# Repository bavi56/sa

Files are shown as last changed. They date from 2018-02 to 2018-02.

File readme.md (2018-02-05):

# Servisní analyzátor s arduino Nano

* 8x 24V digitalni vstup
* 3x analogový vstup pro SCT013

## Firmware

[arduino Nano](./sa.ino)

Odkomentovat pro čitelný výpis do serial monitoru:
```c++
#define DEBUG
```

Seznam součástek [zde](./eagle/partlist.txt).

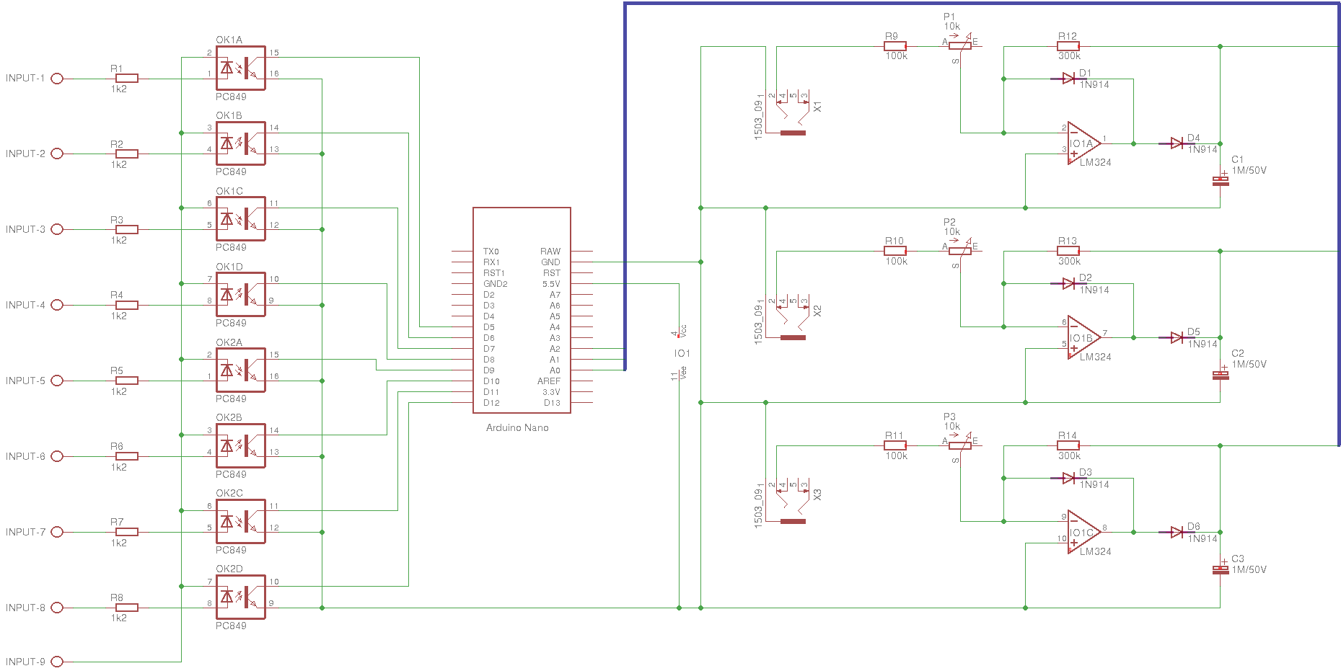
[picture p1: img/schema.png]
Schéma


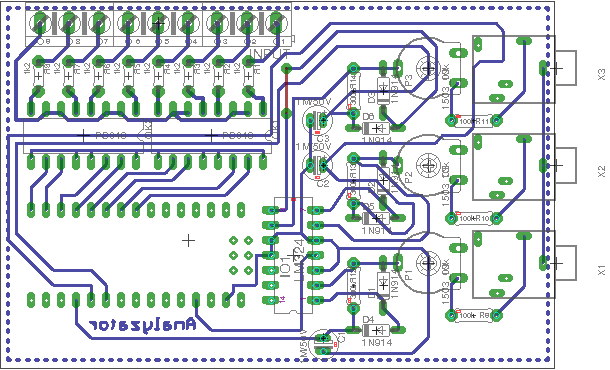
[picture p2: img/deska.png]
Deska


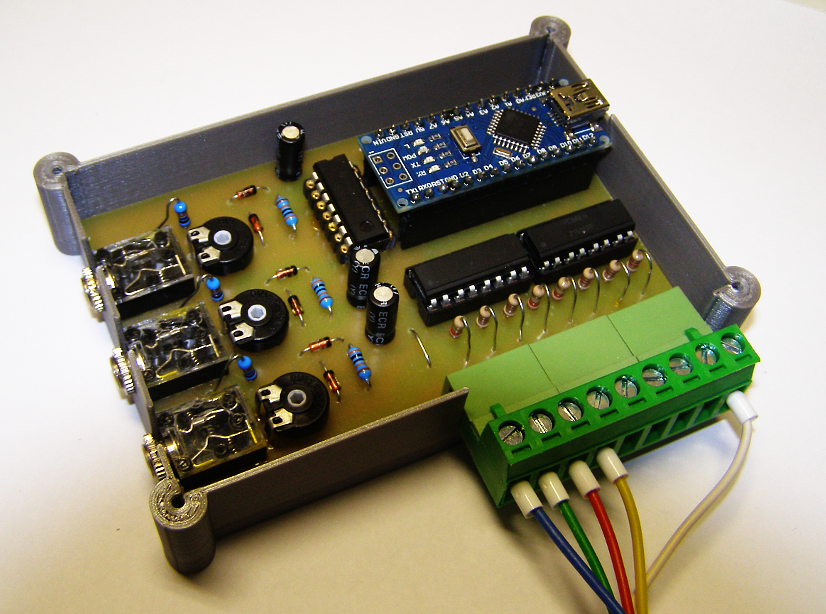
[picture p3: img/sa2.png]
Strana soucastek


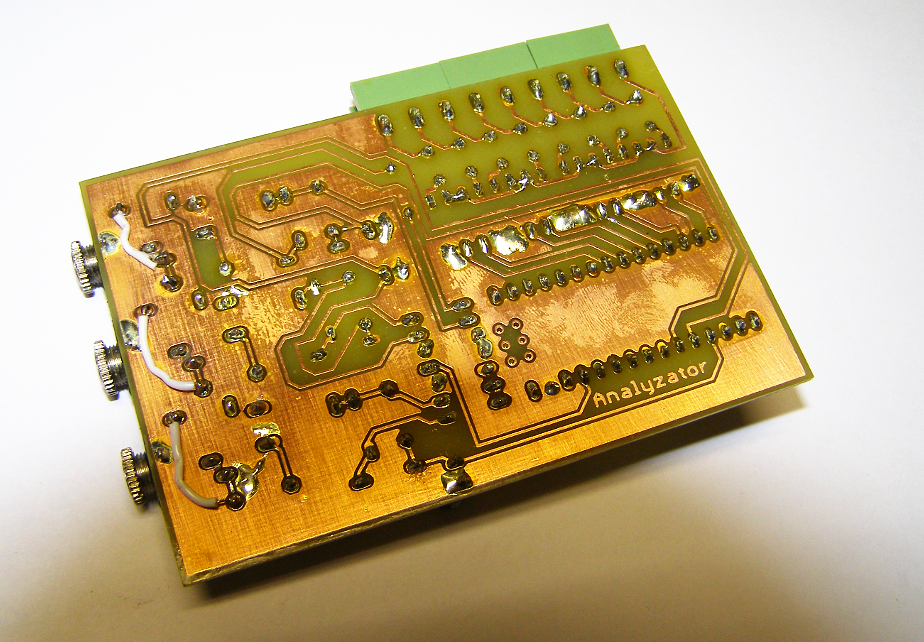
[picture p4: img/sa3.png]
Strana spoju


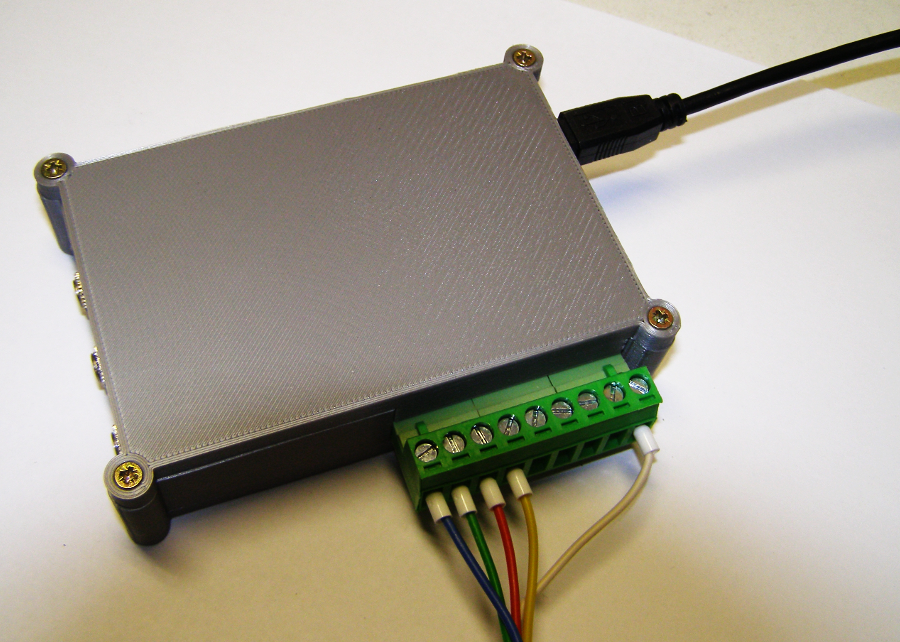
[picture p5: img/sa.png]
Sestaveno


## Zobrazení

* ### processing [zde](./processing/sa_java.pde)

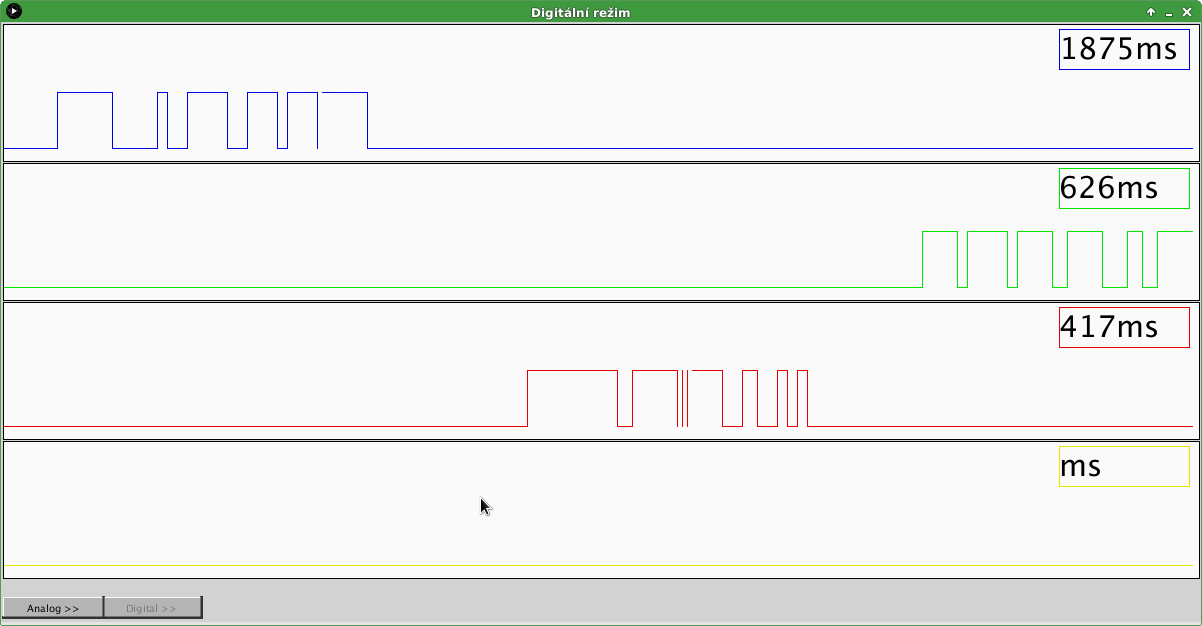
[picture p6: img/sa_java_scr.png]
Processing


* ### python [zde](./sa.pyw) (potřeba stáhnout modul [pygraf](https://github.com/blindp/pygraf) a mít nainstalovaný tkinter)

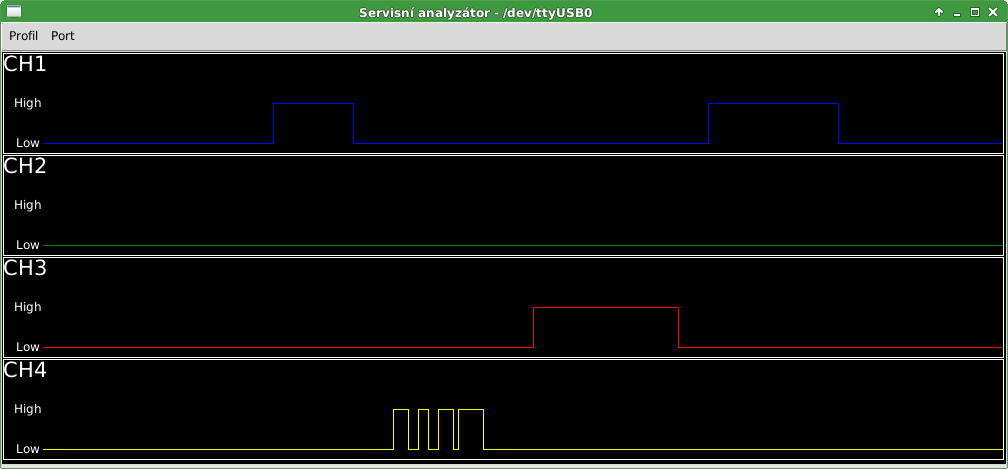
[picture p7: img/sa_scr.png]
SaPy


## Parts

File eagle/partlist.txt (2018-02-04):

Partlist

Exported from s_analyzer.sch at 04.02.18 13:12

EAGLE Version 7.6.0 Copyright (c) 1988-2016 CadSoft

Assembly variant: 

Part     Value          Device       Package  Library       Sheet

C1       1M/50V         1M/50V       C_EL_2   #PaJa_C-el_2  1
C2       1M/50V         1M/50V       C_EL_2   #PaJa_C-el_2  1
C3       1M/50V         1M/50V       C_EL_2   #PaJa_C-el_2  1
D1       1N914          1N4148DO35-7 DO35-7   diode         1
D2       1N914          1N4148DO35-7 DO35-7   diode         1
D3       1N914          1N4148DO35-7 DO35-7   diode         1
D4       1N914          1N4148DO35-7 DO35-7   diode         1
D5       1N914          1N4148DO35-7 DO35-7   diode         1
D6       1N914          1N4148DO35-7 DO35-7   diode         1
INPUT                   AK500/9      AK500/9  #Svorkovnice  1
IO1      LM324          LM324        DIL14    #PaJa_31      1
OK1      PC849          PC849        DIL16    optocoupler   1
OK2      PC849          PC849        DIL16    optocoupler   1
P1       10k            TRIMRPT10V   PT10V    #Trimry       1
P2       10k            TRIMRPT10V   PT10V    #Trimry       1
P3       10k            TRIMRPT10V   PT10V    #Trimry       1
R1       1k2            R-EU_0204/5  0204/5   #Odpory       1
R2       1k2            R-EU_0204/5  0204/5   #Odpory       1
R3       1k2            R-EU_0204/5  0204/5   #Odpory       1
R4       1k2            R-EU_0204/5  0204/5   #Odpory       1
R5       1k2            R-EU_0204/5  0204/5   #Odpory       1
R6       1k2            R-EU_0204/5  0204/5   #Odpory       1
R7       1k2            R-EU_0204/5  0204/5   #Odpory       1
R8       1k2            R-EU_0204/5  0204/5   #Odpory       1
R9       100k           330K         R_7,5    #PaJa_R       1
R10      100k           330K         R_7,5    #PaJa_R       1
R11      100k           330K         R_7,5    #PaJa_R       1
R12      300k           100K         R_7,5    #PaJa_R       1
R13      300k           100K         R_7,5    #PaJa_R       1
R14      300k           100K         R_7,5    #PaJa_R       1
U$1      NANO           NANO         NANO     Arduino-clone 1
X1       1503_09        1503_09      1503_09  con-lumberg   1
X2       1503_09        1503_09      1503_09  con-lumberg   1
X3       1503_09        1503_09      1503_09  con-lumberg   1

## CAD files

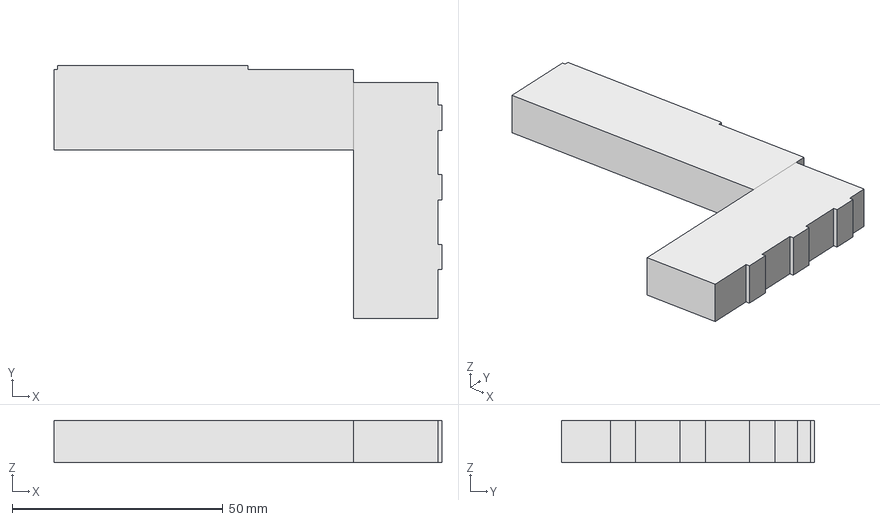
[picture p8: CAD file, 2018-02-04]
freeCAD/krabicka_sa.fcstd
92.0 x 60.0 x 10.0 mm

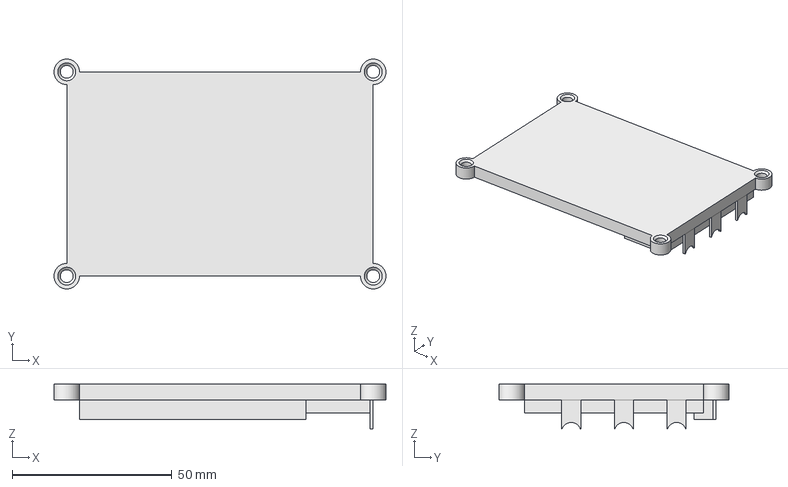
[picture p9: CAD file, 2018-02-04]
freeCAD/vicko_sa.fcstd
104.0 x 72.0 x 14.0 mm

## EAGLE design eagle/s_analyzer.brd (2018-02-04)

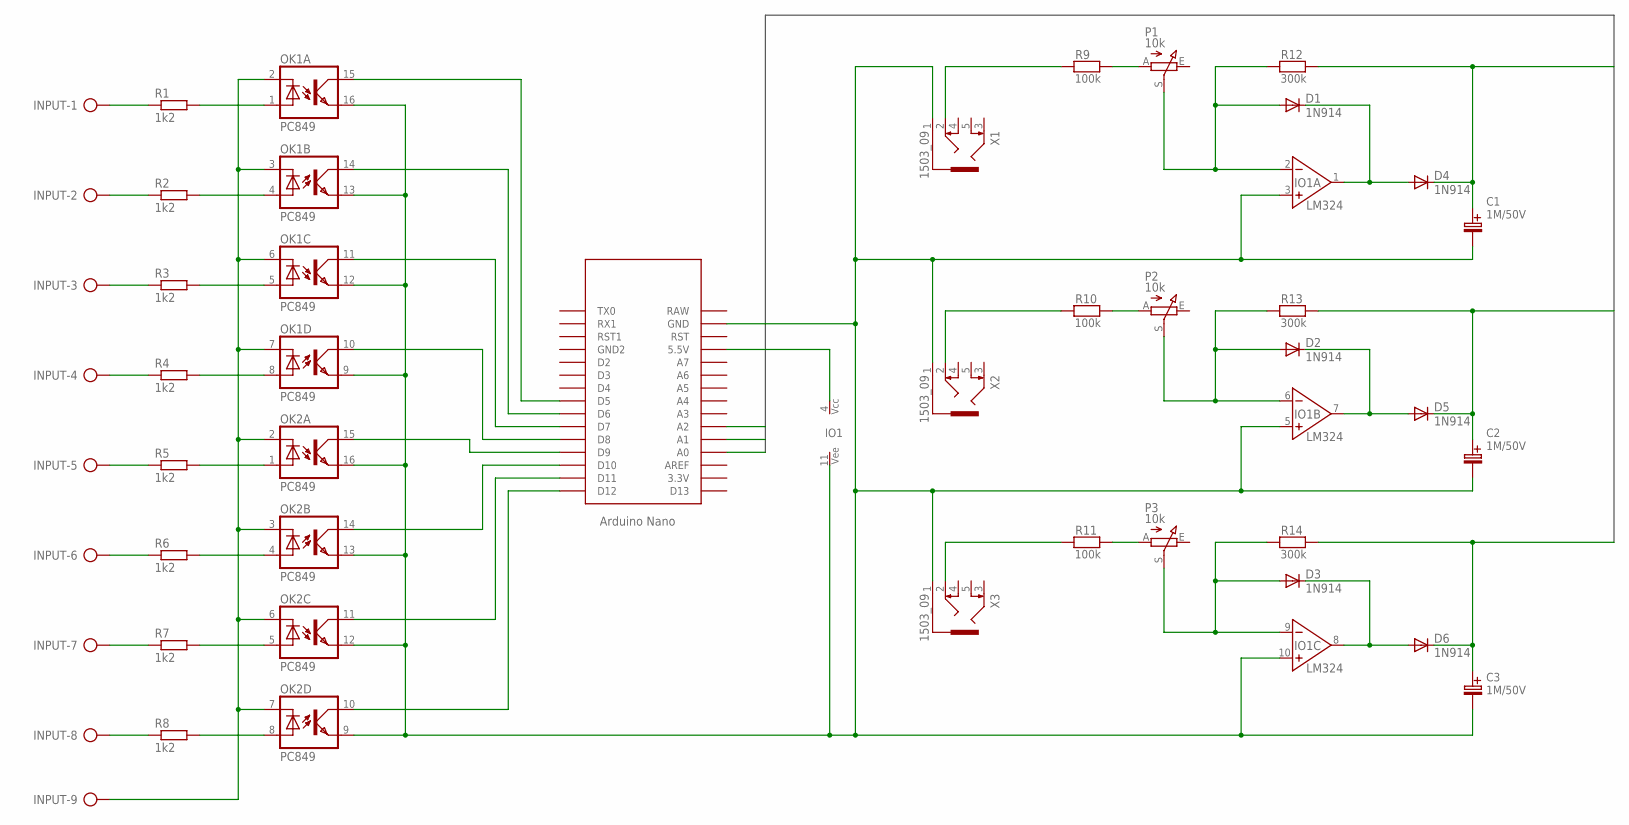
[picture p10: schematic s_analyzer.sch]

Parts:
C1, C2, C3: 1M/50V; C_EL_2
D1, D2, D3, D4, D5, D6: 1N914; DO35-7
INPUT: AK500/9
IO1: LM324; DIL14
OK1, OK2: PC849; DIL16
P1, P2, P3: 10k; PT10V
R1, R2, R3, R4, R5, R6, R7, R8: 1k2; 0204/5
R9, R10, R11: 100k; R_7,5
R12, R13, R14: 300k; R_7,5
U$1: NANO
X1, X2, X3: 1503_09

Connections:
A0: C1.C+ (C_EL+), D4.C, R12.2, U$1.A0
A1: C2.C+ (C_EL+), D5.C, R13.2, U$1.A1
A2: C3.C+ (C_EL+), D6.C, R14.2, U$1.A2
unnamed: INPUT.1, R1.1
unnamed: OK1.1 (A), R1.2
unnamed: INPUT.2, R2.1
unnamed: OK1.4 (A), R2.2
unnamed: INPUT.3, R3.1
unnamed: OK1.5 (A), R3.2
unnamed: INPUT.4, R4.1
unnamed: OK1.8 (A), R4.2
unnamed: INPUT.5, R5.1
unnamed: OK2.1 (A), R5.2
unnamed: INPUT.6, R6.1
unnamed: OK2.4 (A), R6.2
unnamed: INPUT.7, R7.1
unnamed: OK2.5 (A), R7.2
unnamed: INPUT.8, R8.1
unnamed: OK2.8 (A), R8.2
unnamed: INPUT.9, OK1.2 (C), OK1.3 (C), OK1.6 (C), OK1.7 (C), OK2.2 (C), OK2.3 (C), OK2.6 (C), OK2.7 (C)
unnamed: IO1.4 (VCC), U$1.5V (5.5V)
unnamed: OK2.10 (COL), U$1.D12
unnamed: OK2.11 (COL), U$1.D11
unnamed: OK2.14 (COL), U$1.D10
unnamed: OK2.15 (COL), U$1.D9
unnamed: OK1.10 (COL), U$1.D8
unnamed: OK1.11 (COL), U$1.D7
unnamed: OK1.14 (COL), U$1.D6
unnamed: OK1.15 (COL), U$1.D5
unnamed: D1.A, IO1.2 (IN-), P1.S, R12.1
unnamed: P1.A, R9.2
unnamed: D1.C, D4.A, IO1.1 (VYSTUP)
unnamed: R11.1, X3.2
unnamed: P2.A, R10.2
unnamed: D2.A, IO1.6 (IN-), P2.S, R13.1
unnamed: D2.C, D5.A, IO1.7 (VYSTUP)
unnamed: R10.1, X2.2
unnamed: P3.A, R11.2
unnamed: D3.A, IO1.9 (IN-), P3.S, R14.1
unnamed: D3.C, D6.A, IO1.8 (VYSTUP)
unnamed: R9.1, X1.2
unnamed: C1.C- (C_EL-), C2.C- (C_EL-), C3.C- (C_EL-), IO1.3 (NEIN+), IO1.5 (NEIN+), IO1.10 (NEIN+), IO1.11 (VEE), OK1.9 (EMI), OK1.12 (EMI), OK1.13 (EMI), OK1.16 (EMI), OK2.9 (EMI), OK2.12 (EMI), OK2.13 (EMI), OK2.16 (EMI), U$1.GND, X1.1, X2.1, X3.1

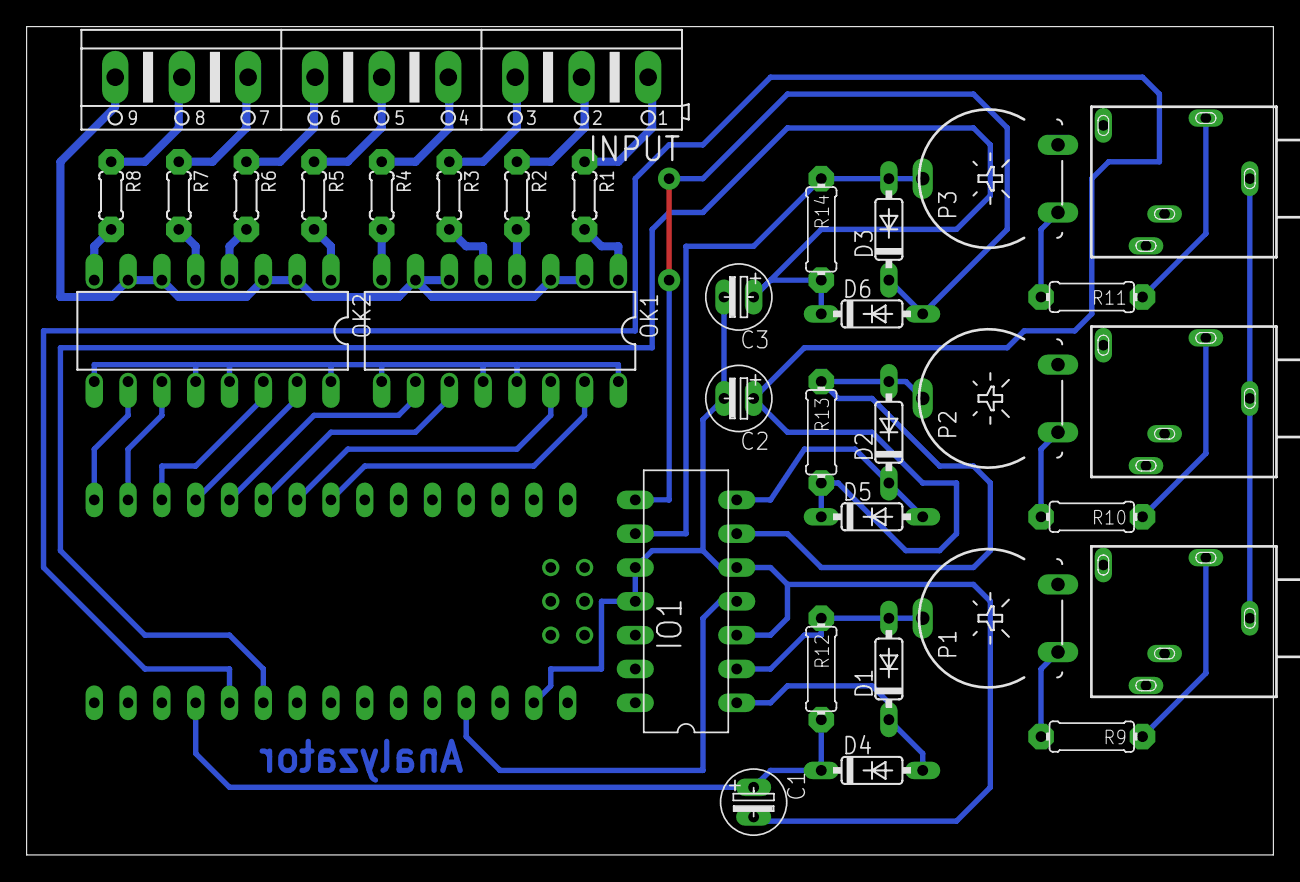
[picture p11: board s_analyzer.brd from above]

Board: 2 copper layers, 93.6 x 62.2 mm, 34 parts (0 on the bottom side), 42 nets.

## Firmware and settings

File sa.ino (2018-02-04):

/*Firmware pro servisni analyzator verze 1
 * 8x 24V digitalni vstup
 * 3 analogove (prevodnik proudovy transformator SCT013 www.yhdc.com (0-5A -> 0-1V))
 * Blind Pew <blind.pew96@gmail.com> 2016 GNU GPL v3
 */

//#define DEBUG
#define BRATE 115200
#define MIN_ADC 0
#define MAX_ADC 1023
#define MIN_ANALOG  0
#define MAX_ANALOG  5000
#ifdef DEBUG
  #define DELAY_DIGITAL 1000
  #define DELAY_ANALOG 1000
#else
  #define DELAY_DIGITAL 5
  #define DELAY_ANALOG  50
#endif
 
byte ovlByte = 0;
bool digital = true;  //rezim true - digitalni | false - analogovy
byte digPins[] = {5,6,7,8,9,10,11,12}; //24V vstupy 
byte anaPins[] = {A0,A1,A2};  //proudove vstupy
byte stav;  //byte 24V vstupu

void setup() {
  Serial.begin(BRATE);
  for(int i=0;i<sizeof(digPins);i++) {
    pinMode(digPins[i],INPUT_PULLUP);
  }
}

void loop() {
  if(Serial.available() > 0) {
    ovlByte = Serial.read();
    if(ovlByte == 'D') digital = true;
    if(ovlByte == 'A') digital = false;
  }
  
  if(digital) {
    for(int i=0;i<8;i++) {
      bitWrite(stav,i,!digitalRead(digPins[i]));
      #ifdef DEBUG
        Serial.print(!digitalRead(digPins[i]));
      #endif
    }
    #ifdef DEBUG    
      Serial.print("-->>");
      Serial.println(stav);
    #else
      Serial.write(stav);
    #endif
    delay(DELAY_DIGITAL);
  }
  else {
    for(int i=0;i<3;i++) {
      Serial.print(map(analogRead(i),MIN_ADC,MAX_ADC,MIN_ANALOG,MAX_ANALOG));
      Serial.print(";");
    }
    Serial.println("");
    delay(DELAY_ANALOG);
  }
}

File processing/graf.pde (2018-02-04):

//Plny graf
class GrafPlny {
  int lmin,lmax,dilku,inc_d,t_size;
  float xpos,ypos,xsize,ysize;
  float[] level;
  color bck,frg,ink;
  boolean auto;
  
  //konstruktor
  GrafPlny(float x_p, float y_p, float x_s,float y_s, color barva,int nula, int maximum) { //vytvori novy graf
    xpos = x_p;  //souradnice noveho grafu
    ypos = y_p;
    xsize = x_s;  //velikost noveho grafu
    ysize = y_s;
    level = new float[int(xsize)]; //vytvori pole o delce sire grafu
    dilku = 15;  //kolik dilku chci mit na stupnici
    inc_d = 1;
    bck = 250;  //barva pozadi
    frg = 0;    //barva popredi
    ink = barva;  //barva grafu
    t_size = 10;  //velikost pisma
    auto = false;
    if(maximum > 0) {
      lmin = nula;
      lmax = maximum;
    }
    else {
      auto = true;
    }
    
  }
  
  void kresli(float l) {
    textAlign(LEFT, BASELINE);
    strokeWeight(1);
    noStroke();
    fill(bck);
    rect(xpos,ypos,xsize,ysize);
    
    if(auto) {
      //urceni min-max hodnoty pro graf
      if(l < lmin) lmin = round(l);
      if(l > lmax) lmax = round(l);
    }
    //posunuti pole o jednu hodnotu zpet (vytvori misto pro novou hodnotu)
    for (int i = 1; i < level.length; i++) {
      level[i-1] = level[i];
    }
    level[level.length-1] = l; //na posledni mmisto prida novou hodnotu
    
    //vykresli cely graf
    for (int i = 0; i < level.length; i++) {
      float yg = map(level[i],lmin,lmax,ypos+ysize,ypos);
      stroke(ink);
      line(i+xpos,ypos+ysize,i+xpos,yg);
    }
    //vykresli stupnici
    fill(bck);
    stroke(frg);
    rect(xpos,ypos,50,ysize);
    stroke(frg);
    if(lmax > dilku) {
      inc_d = lmax/dilku;
    }
    else {
      inc_d = 1;
    }
    for (int i = lmin; i < lmax; i +=inc_d) {
      float ydilek = map(i,lmin,lmax,ypos+ysize,ypos);
      line(xpos+30,ydilek,xpos+50,ydilek);
      for (float x = xpos+50; x < xpos+xsize; x +=5) {
        point(x,ydilek);
      }
      fill(frg);
      textSize(t_size);
      text(floor(i),xpos+5,ydilek-1);
      
    }
    
    //zobrazeni aktualni hodnoty
    fill(bck);
    stroke(ink);
    rect(xpos+xsize-130,ypos+5,120,40);
    fill(frg);
    textSize(30);
    text(l,xpos+xsize-130,ypos+35);
    
    noFill();
    stroke(frg);
    //ram
    rect(xpos,ypos,xsize,ysize);
    
  }
}




//cara
class Graf {
  int lmin,lmax,dilku,inc_d,t_size;
  float xpos,ypos,xsize,ysize;
  float[] level;
  color bck,frg,ink;
  boolean auto;
  
  //konstruktor
  Graf(float x_p, float y_p, float x_s,float y_s, color barva,int nula, int maximum) { //vytvori novy graf
    xpos = x_p;  //souradnice noveho grafu
    ypos = y_p;
    xsize = x_s;  //velikost noveho grafu
    ysize = y_s;
    level = new float[int(xsize)]; //vytvori pole o delce sire grafu
    dilku = 15;  //kolik dilku chci mit na stupnici
    inc_d = 1;
    bck = 250;  //barva pozadi
    frg = 0;    //barva popredi
    ink = barva;  //barva grafu
    t_size = 10;  //velikost pisma
    auto = false;
    if(maximum > 0) {
      lmin = nula;
      lmax = maximum;
    }
    else {
      auto = true;
    }
    
  }
  
  void kresli(float l) {
    textAlign(LEFT, BASELINE);
    strokeWeight(1);
    noStroke();
    fill(bck);
    rect(xpos,ypos,xsize,ysize);
    
    if(auto) {
      //urceni min-max hodnoty pro graf
      if(l < lmin) lmin = round(l);
      if(l > lmax) lmax = round(l);
    }
    //posunuti pole o jednu hodnotu zpet (vytvori misto pro novou hodnotu)
    for (int i = 1; i < level.length; i++) {
      level[i-1] = level[i];
    }
    level[level.length-1] = l; //na posledni mmisto prida novou hodnotu
    float xg_p = 0;
    float yg_p = 0;
    //vykresli cely graf
    for (int i = 0; i < level.length; i++) {
      float xg = map(i, 0, level.length,xpos,xsize);
      float yg = map(level[i],lmin,lmax,ypos+ysize,ypos);
      if((xg_p == 0) && (yg_p == 0)) {
        xg_p = xg;
        yg_p = yg;
      }
      stroke(ink);
      line(xg_p,yg_p,xg,yg);
      xg_p = xg;
      yg_p = yg;
    }
    //vykresli stupnici
    fill(bck);
    stroke(frg);
    rect(xpos,ypos,50,ysize);
    stroke(frg);
    if(lmax > dilku) {
      inc_d = lmax/dilku;
    }
    else {
      inc_d = 1;
    }
    for (int i = lmin; i < lmax; i +=inc_d) {
      float ydilek = map(i,lmin,lmax,ypos+ysize,ypos);
      line(xpos+30,ydilek,xpos+50,ydilek);
      for (float x = xpos+50; x < xpos+xsize; x +=5) {
        point(x,ydilek);
      }
      fill(frg);
      textSize(t_size);
      text(floor(i),xpos+5,ydilek-1);
    }
    
    //zobrazeni aktualni hodnoty
    fill(bck);
    stroke(ink);
    rect(xpos+xsize-130,ypos+5,120,40);
    fill(frg);
    textSize(30);
    text(l,xpos+xsize-130,ypos+35);
    
    
    noFill();
    stroke(frg);
    rect(xpos,ypos,xsize,ysize);
    
  }
}





//vrati vysku grafu
float vyska_y(boolean stav, float sirka, float offset) {
  
  if(stav) {
    return (sirka/2)+offset;
  }
  else {
    return (sirka/1.1)+offset;
  }
}

class Digital {
  long ts_up, ts_dw;
  float xpos,ypos,xsize,ysize;
  boolean[] level;
  color bck,frg,ink;
  String msg;
  
  //kostruktor
  Digital(float x_p, float y_p, float x_s,float y_s, color barva) { //vytvori novy graf
    xpos = x_p;  //souradnice noveho grafu
    ypos = y_p;
    xsize = x_s;  //velikost noveho grafu
    ysize = y_s;
    level = new boolean[int(xsize)/5]; //vytvori pole o delce sire grafu/5
    //level = new boolean[500];
    bck = 250;  //barva pozadi
    frg = 0;    //barva popredi
    ink = barva;  //barva grafu
    msg = "ms";
    
  }
  void kresli(boolean l) {
    textAlign(LEFT, BASELINE);
    strokeWeight(1);
    noStroke();
    fill(bck);
    rect(xpos,ypos,xsize,ysize);
    
    for (int i = 1; i<level.length; i++) {
      level[i-1] = level[i];
    }
    
    //mereni doby
    if(!level[level.length-2] && l) {
      ts_up = millis();
    }
    if(level[level.length-2] && !l) {
      ts_dw = millis();
      msg = str(int(ts_dw - ts_up))+"ms";
    }
    level[level.length-1] = l; //prida posledni
    
    float xg = 0;
    float yg = 0;
    float xg_p = 0;
    float yg_p = 0;
    
    boolean zmena = false;
    //nakresleni grafu
    for (int i = 1; i < level.length; i++) {
      if(zmena) {
        xg_p = map(i-2, 0, level.length, xpos, xsize);
        zmena = false;
      }
      else {
        xg_p = map(i-1, 0, level.length, xpos, xsize);
      }
      xg = map(i, 0, level.length, xpos, xsize);
      
      //vyska
      yg_p = vyska_y(level[i-1],ysize,ypos);
      yg = vyska_y(level[i],ysize,ypos);
      
      stroke(ink);
      if(level[i-1] != level[i]) {
        xg = xg_p;
        zmena = true;
      }
      line(xg_p,yg_p,xg,yg);
    }
    
    //zobrazeni casu ms
    fill(bck);
    stroke(ink);
    rect(xpos+xsize-140,ypos+5,130,40);
    fill(frg);
    textSize(30);
    text(msg,xpos+xsize-140,ypos+35);
    
    
    noFill();
    stroke(frg);
    rect(xpos,ypos,xsize,ysize);
  }
}

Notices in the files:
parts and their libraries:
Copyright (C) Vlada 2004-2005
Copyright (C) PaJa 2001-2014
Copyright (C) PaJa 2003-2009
